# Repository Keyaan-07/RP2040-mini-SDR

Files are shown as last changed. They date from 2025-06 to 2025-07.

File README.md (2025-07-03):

# RP2040 Mini SDR
This is an SDR, as the name says, and it can function in the FM, Airband and NOAA-APT bands ONLY AS A RECEIVER. This is completely legal to make and use.  
I have used RP2040 and ADE-11X+ mixer and SI5351 controllable clock. I thought that i would use a PCB trace USB but then i didn't do it because it would make the board cost go BOOOOM. So, normal USB-A.

I am in no way an RF expert and would love it if someone pointed out my errors and mailed them to [me](mailto:keyaan.1911@gmail.com) or DM on [hackclub](https://hackclub.com) Slack ```@Keyaan```

I think I am gonna make another RF board that could legally transmit too! but that's just an idea for now. 

I am not making a 3D model for this project as i feel this is not required for now. 

## Why I chose to make this project
I have always wanted to try out stuff with RF, especially receiving images from NOAA with my own stuff(I have used [WebSDRs](https://websdr.org) before).  
So i thought that why not make it FM too. And then GPT told me i could legally listen to airband signals too. 

So, i planned to make out an SDR using the goated RP2040 chip and a few mixers and oscillators.  

I have used an SMA connector as it is the most common one i think. 

## How to make and bake it!
Your take the gerber files from this repository and then you upload them to your desired PCB manufacturer. I am using [PCB Power](htttps://pcbpower.com) as they support hcb cards and are only about 350km from my home. and you also order the parts listen in the BOM, i wont order everything, as i have a few things from my previous orders. so, in the BOM, there is Do Not Order column(DNO) that shows what i wont order but you would have to order if you wanna make it. Then you prep the PCB with solder paste. Then you just use the ibom from this repo and place the components and bake it up.

I have set prices to 0 for the components that i have already but i have linked them down.

# Images:
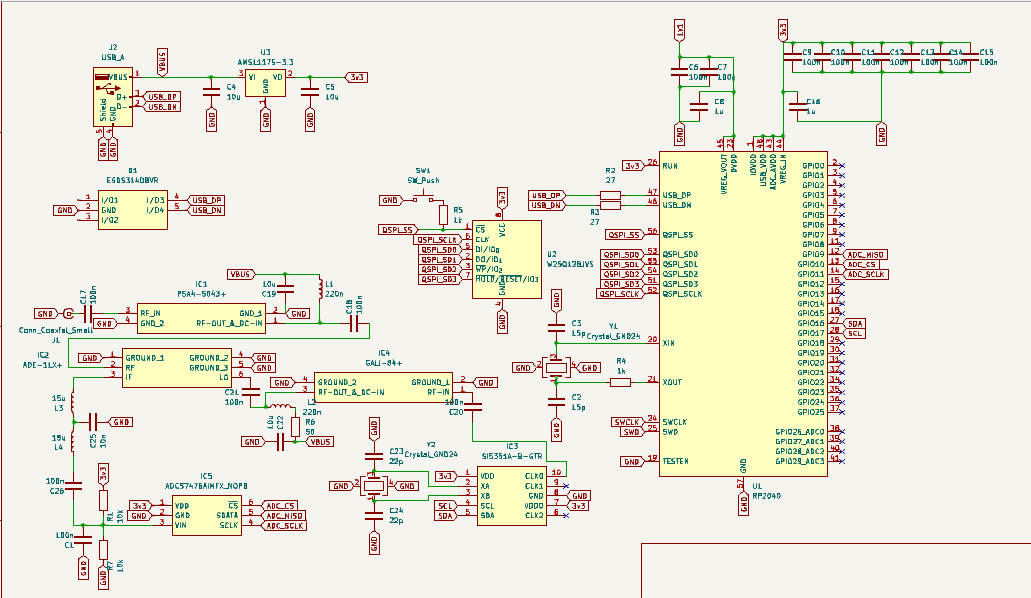
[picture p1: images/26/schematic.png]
Schematic


PCB final prolly

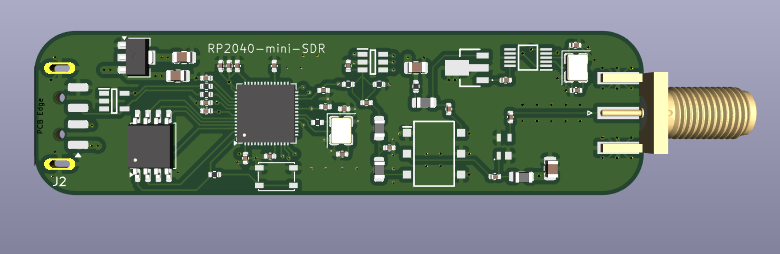
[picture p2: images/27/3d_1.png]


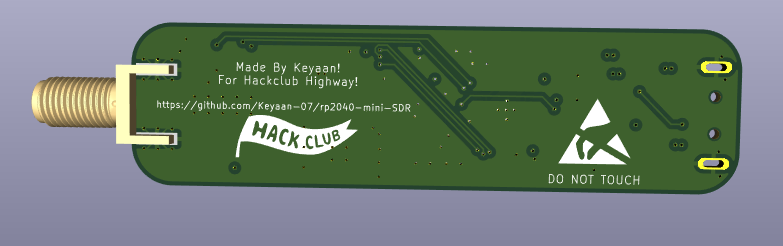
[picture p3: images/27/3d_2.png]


# BOM
|ITEM NAME |ITEM PRICE|FUNCTION |URL |OTHERS|
|---|---|---|---|---|
|PCB Manufacturing(4 Layer)+Stencil|$29.14 |The Main PCB + Stencil |https://jlcpcb.com | | | |
|PCB Components |$23.49 |Components on PCB |https://lcsc.com | |
|Tape Measure and SMA Cable|$5.57 |tape measure for a dipole antenna and sma to connect it to the PCB|https://www.amazon.in/FREEMANS-IKON-5m-Unbreakable-Bi-material/dp/B010M5GQ78/ , https://www.amazon.in/3AN-Telecom-Coaxial-Extension-Security/dp/B08GKXS915/| |
|Total |$58.20 | | | |  

### Update 2: i updated the stencil to be ordered from jlcpcb instead of pcbpower, as it was wayy expensive. Thank You.

### Update: I updated the pcb manufacturer from pcbpower to jlcpcb as pcbpower was way too expensive, and i didn't change the stencil if i add stencil on jlcpcb, the stencil+pcb would jump from $15 to $52 because shipping would be so much more, so i will order pcb from jlc for $15 incl. shipping and the stencil from pcbpower only because that would make it overall cheaper. Basically both from jlc would have been $52 and pcb from jlc and stencil form pcbpower is $42, so we save $10.
----
### Note: There are a few resistors and capacitors, which had very high minimum order quantity(MOQ), about 100 pieces so i had to forcefully include those, which i will be utilising in my next highway projects. And tbh the prices were very less(about $0.002 per piece) so i think it is alright.

# PCB Component Breakdown

|Id |Designator |Designation |MPN |Footprint |DNO - Do Not Order|DNP|MOQ|price |Quantity|Amount|LCSC Part No.|Supplier Link |
|---|---|---|---|---|---|---|---|---|---|---|---|---|
|1  |C1, C10, C11, C12, C13, C14, C15, C17, C18, C20, C21, C26, C6, C7, C9|100n |GRM155R61H104JE14D |402 |Yes |No |-  |0 |15 |0 | |https://lcsc.com/product-detail/Multilayer-Ceramic-Capacitors-MLCC-SMD-SMT_Murata-Electronics-GRM155R61H104JE14D_C426067.html |
|2  |C16, C8 |1u |GRM155R61H105KE05D |402 |Yes |No |-  |0 |2 |0 | |https://lcsc.com/product-detail/Multilayer-Ceramic-Capacitors-MLCC-SMD-SMT_Murata-Electronics-GRM155R61H105KE05D_C1518208.html |
|3  |C19, C22, C4, C5 |10u |CL21A106KBYQNNE |805 |No |No |Yes|0.0509|10 |0.509 | |https://lcsc.com/product-detail/Multilayer-Ceramic-Capacitors-MLCC-SMD-SMT_Samsung-Electro-Mechanics-CL21A106KBYQNNE_C2932476.html|
|4  |C2, C3 |15p |GJM1555C1H150FB01D |402 |Yes |No |-  |0 |2 |0 | |https://lcsc.com/product-detail/Multilayer-Ceramic-Capacitors-MLCC-SMD-SMT_Murata-Electronics-GJM1555C1H150FB01D_C441742.html |
|5  |C23, C24 |22p |GJM1555C1H220FB01D |402 |No |No |Yes|0.0379|20 |0.758 | |https://lcsc.com/product-detail/Multilayer-Ceramic-Capacitors-MLCC-SMD-SMT_Murata-Electronics-GJM1555C1H220FB01D_C882567.html |
|6  |C25 |10n |CC0402JRX7R9BB103 |402 |No |No |Yes|0.0016|100 |0.16  | |https://lcsc.com/product-detail/Multilayer-Ceramic-Capacitors-MLCC-SMD-SMT_YAGEO-CC0402JRX7R9BB103_C272878.html |
|7  |D1 |ESDS314DBVR |ESDS314DBVR |ESDS314BVR_SOT95P280X145-5N |Yes |No |-  |0 |1 |0 | |https://lcsc.com/product-detail/ESD-and-Surge-Protection-TVS-ESD_Texas-Instruments-ESDS314DBVR_C1847859.html |
|8  |IC1 |PSA4-5043+ |PSA4-5043+ |PSA45043 |No |No |No |2.22  |1 |2.22  | |https://lcsc.com/product-detail/RF-Amplifiers_Mini-Circuits-PSA4-5043_C5240848.html |
|9  |IC2 |ADE-11X+ |ADE-11X+ |ADE-11X+_SOTFL254P691X284-6N |No |No |No |4.87  |1 |4.87  | |https://lcsc.com/product-detail/RF-Mixers_Mini-Circuits-ADE-11X_C3176636.html |
|10 |IC3 |SI5351A-B-GTR |SI5351A-B-GTR |SI5351_SOP50P490X110-10N |No |No |No |0.92  |1 |0.92  | |https://lcsc.com/product-detail/Clock-Generators-PLLs-Frequency-Synthesizers_SKYWORKS-SILICON-LABS-SI5351A-B-GTR_C504891.html |
|11 |IC4 |GALI-84+ |GALI-84+ |GALI5 |No |No |No |4.3 |1 |4.3 | |https://lcsc.com/product-detail/RF-Amplifiers_Mini-Circuits-GALI-84_C3193261.html |
|12 |IC5 |ADCS7476AIMFX_NOPB|ADCS7476AIMFX_NOPB |ADCS7476_SOT95P280X145-6N |No |No |No |1.9 |1 |1.9 | |https://lcsc.com/product-detail/Analog-to-Digital-Converters-ADC_Texas-Instruments-ADCS7476AIMFX-NOPB_C91530.html |
|13 |J1 |Conn_Coaxial_Small|BWSMA-KE-P001 |SMA_Amphenol_132289_EdgeMount |No |No |No |0.38  |1 |0.38  | |https://lcsc.com/product-detail/Coaxial-Connectors-RF_BAT-WIRELESS-BWSMA-KE-P001_C496550.html |
|14 |J2 |USB_A |USB-212-BCW |USB_A_Connfly_DS1098_Horizontal |No |No |Yes|0.0819|5 |0.4095| |https://lcsc.com/product-detail/USB-Connectors_XUNPU-USB-212-BCW_C720521.html |
|15 |L1, L2 |220n |FEC0805CP-R22G-LRH |805 |No |No |Yes|0.0618|10 |0.618 | |https://lcsc.com/product-detail/Inductors-SMD_PSA-Prosperity-Dielectrics-FEC0805CP-R22G-LRH_C346387.html |
|16 |L3, L4 |15u |YWLD2012-150K |805 |No |No |Yes|0.0391|10 |0.391 | |https://lcsc.com/product-detail/Inductors-SMD_YJYCOIN-YWLD2012-150K_C5339219.html |
|17 |R1, R7 |10k |RCS040210K0FKED |402 |Yes |No |-  |0 |2 |0 | |https://lcsc.com/product-detail/Chip-Resistor-Surface-Mount_Vishay-Intertech-RCS040210K0FKED_C3020235.html |
|18 |R2, R3 |27 |ERJ2GEJ270X |402 |Yes |No |-  |0 |2 |0 | |https://lcsc.com/product-detail/Chip-Resistor-Surface-Mount_PANASONIC-ERJ2GEJ270X_C278580.html |
|19 |R4, R5 |1k |ERJPA2F1001X |402 |Yes |No |-  |0 |2 |0 | |https://lcsc.com/product-detail/Chip-Resistor-Surface-Mount_PANASONIC-ERJPA2F1001X_C427241.html |
|20 |R6 |50 |RT0402BRE0750RL |402 |No |No |Yes|0.0207|20 |0.414 | |https://lcsc.com/product-detail/Chip-Resistor-Surface-Mount_YAGEO-RT0402BRE0750RL_C853312.html |
|21 |SW1 |SW_Push |PTS810SJM250SMTRLFS |SW_SPST_PTS810 |No |No |No |0.6 |3 |1.8 | |https://lcsc.com/product-detail/Tactile-Switches_C-K-PTS810SJM250SMTRLFS_C116501.html |
|22 |U1 |RP2040 |RP2040 |QFN-56-1EP_7x7mm_P0.4mm_EP3.2x3.2mm|No |No |No |1.131 |1 |1.131 | |https://lcsc.com/product-detail/Microcontrollers-MCU-MPU-SOC_Raspberry-Pi-RP2040_C2040.html |
|23 |U2 |W25Q128JVS |W25Q128JVS |SOIC-8_5.3x5.3mm_P1.27mm |Yes |No |-  |0 |1 |0 | |https://lcsc.com/product-detail/NOR-FLASH_Winbond-Elec-W25Q128JVSIM_C2613930.html |
|24 |U3 |AMS1117S-3.3 |AMS1117S-3.3 |SOT-89-3 |yes |No |-  |0 |1 |0 | |https://lcsc.com/product-detail/Voltage-Regulators-Linear-Low-Drop-Out-LDO-Regulators_JSMSEMI-AMS1117S-3-3_C917152.html |
|25 |Y1 |Crystal_GND24 |ABM8-272-T3 |Crystal_SMD_3225-4Pin_3.2x2.5mm |No |No |No |0.3731|2 |0.7462| | |
|26 |Y2 |Crystal_GND24 |XXGBBCNANF-25.000000MHZ|Crystal_SMD_3225-4Pin_3.2x2.5mm |No |No |Yes|0.1459|5 |0.7295| |https://lcsc.com/product-detail/Crystals_TAITIEN-Elec-XXGBBCNANF-25-000000MHZ_C521601.html |
| |Rounding Errors |1.2338 |USD | | | | | | | | | |
| |Shipping |3.74 |USD | | | | | | | | | |
| |Total |23.49 |USD | | | | | | | | | |

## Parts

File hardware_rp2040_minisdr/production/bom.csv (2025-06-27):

Designator | Footprint | Quantity | Value | LCSC Part #
C1, C10, C11, C12, C13, C14, C15, C17, C18, C20, C21, C26, C6, C7, C9 | 402 | 15 | 100n
C16, C8 | 402 | 2 | 1u
C19, C22, C4, C5 | 805 | 4 | 10u
C2, C3 | 402 | 2 | 15p
C23, C24 | 402 | 2 | 22p
C25 | 402 | 1 | 10n
D1 | ESDS314BVR_SOT95P280X145-5N | 1 | ESDS314DBVR
IC1 | PSA45043 | 1 | PSA4-5043+
IC2 | ADE-11X+_SOTFL254P691X284-6N | 1 | ADE-11X+
IC3 | SI5351_SOP50P490X110-10N | 1 | SI5351A-B-GTR
IC4 | GALI5 | 1 | GALI-84+
IC5 | ADCS7476_SOT95P280X145-6N | 1 | ADCS7476AIMFX_NOPB
J1 | SMA_Amphenol_132289_EdgeMount | 1 | Conn_Coaxial_Small
J2 | USB_A_Connfly_DS1098_Horizontal | 1 | USB_A
L1, L2 | 805 | 2 | 220n
L3, L4 | 805 | 2 | 15u
R1, R7 | 402 | 2 | 10k
R2, R3 | 402 | 2 | 27
R4, R5 | 402 | 2 | 1k
R6 | 402 | 1 | 50
SW1 | SW_SPST_PTS810 | 1 | SW_Push
U1 | QFN-56-1EP_7x7mm_P0.4mm_EP3.2x3.2mm | 1 | RP2040
U2 | SOIC-8_5.3x5.3mm_P1.27mm | 1 | W25Q128JVS
U3 | SOT-89-3 | 1 | AMS1117S-3.3
Y1, Y2 | Crystal_SMD_3225-4Pin_3.2x2.5mm | 2 | Crystal_GND24

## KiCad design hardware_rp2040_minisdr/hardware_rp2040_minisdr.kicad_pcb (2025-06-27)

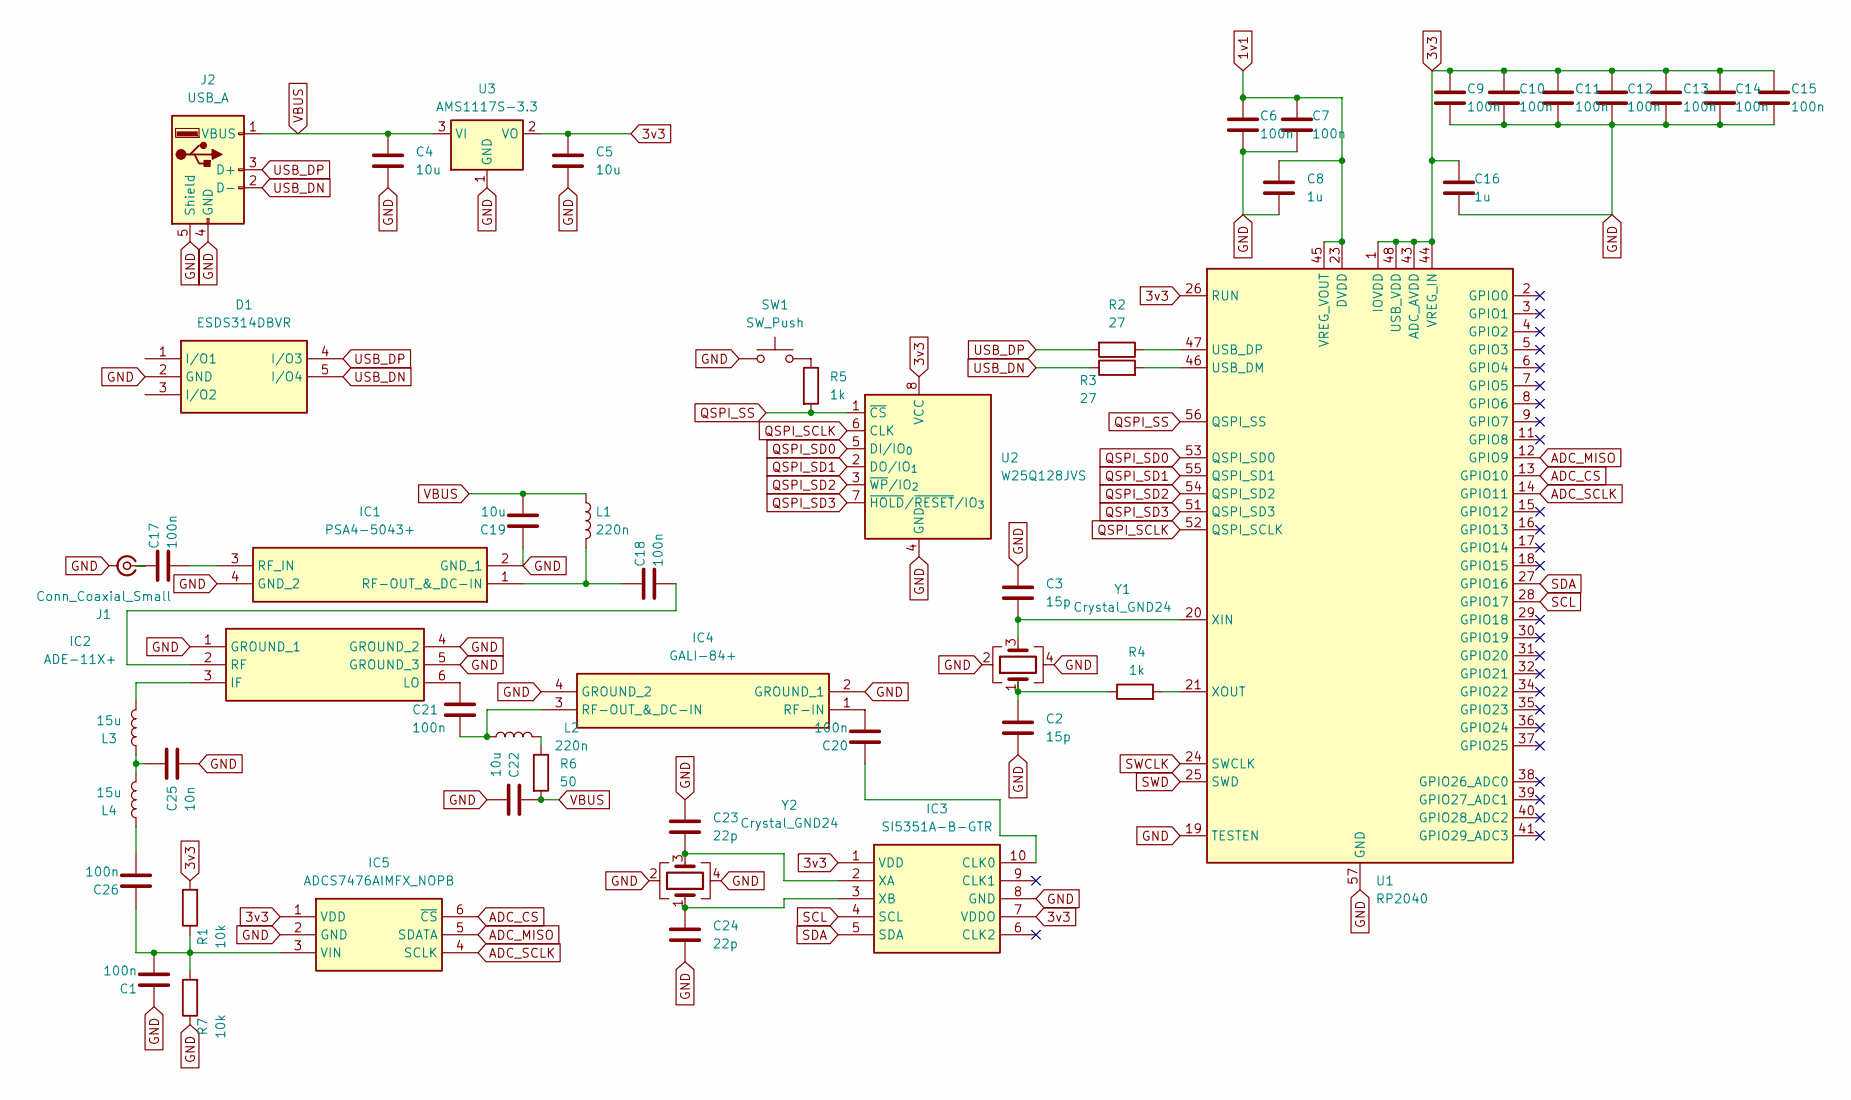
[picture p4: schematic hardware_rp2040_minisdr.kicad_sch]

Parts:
C1, C6, C7, C9, C10, C11, C12, C13, C14, C15, C17, C18, C20, C21, C26: 100n; C_0402_1005Metric
C2, C3: 15p; C_0402_1005Metric
C4, C5, C19, C22: 10u; C_0805_2012Metric
C8, C16: 1u; C_0402_1005Metric
C23, C24: 22p; C_0402_1005Metric
C25: 10n; C_0402_1005Metric
D1: ESDS314DBVR; ESDS314BVR_SOT95P280X145-5N; Mouser Part Number 595-ESDS314DBVR
IC1: PSA4-5043+; PSA45043; Mouser Part Number 139-PSA4-5043
IC2: ADE-11X+; ADE-11X+_SOTFL254P691X284-6N; Mouser Part Number 139-ADE-11X
IC3: SI5351A-B-GTR; SI5351_SOP50P490X110-10N; Mouser Part Number 634-SI5351A-B-GTR
IC4: GALI-84+; GALI5; Mouser Part Number 139-GALI-84
IC5: ADCS7476AIMFX_NOPB; ADCS7476_SOT95P280X145-6N; Mouser Part Number 926-ADCS7476AIMFXNPB
J1: Conn_Coaxial_Small; SMA_Amphenol_132289_EdgeMount
J2: USB_A; USB_A_Connfly_DS1098_Horizontal
L1, L2: 220n; L_0805_2012Metric
L3, L4: 15u; L_0805_2012Metric
R1, R7: 10k; R_0402_1005Metric
R2, R3: 27; R_0402_1005Metric
R4, R5: 1k; R_0402_1005Metric
R6: 50; R_0402_1005Metric
SW1: SW_Push; SW_SPST_PTS810
U1: RP2040; QFN-56-1EP_7x7mm_P0.4mm_EP3.2x3.2mm
U2: W25Q128JVS; SOIC-8_5.3x5.3mm_P1.27mm
U3: AMS1117S-3.3; SOT-89-3
Y1, Y2: Crystal_GND24; Crystal_SMD_3225-4Pin_3.2x2.5mm

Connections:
1v1: C6.1, C7.1, C8.1, U1.23 (DVDD), U1.45 (VREG_VOUT), U1.50 (DVDD)
3v3: C5.1, C9.1, C10.1, C11.1, C12.1, C13.1, C14.1, C15.1, C16.1, IC3.1 (VDD), IC3.7 (VDDO), IC5.1 (VDD), R1.2, U1.1 (IOVDD), U1.10 (IOVDD), U1.22 (IOVDD), U1.26 (RUN), U1.33 (IOVDD), U1.42 (IOVDD), U1.43 (ADC_AVDD), U1.44 (VREG_IN), U1.48 (USB_VDD), U1.49 (IOVDD), U2.8 (VCC), U3.2 (VO)
ADC_CS: IC5.6 (~CS), U1.13 (GPIO10)
ADC_MISO: IC5.5 (SDATA), U1.12 (GPIO9)
ADC_SCLK: IC5.4 (SCLK), U1.14 (GPIO11)
GND: C1.1, C2.2, C3.1, C4.2, C5.2, C6.2, C7.2, C8.2, C9.2, C10.2, C11.2, C12.2, C13.2, C14.2, C15.2, C16.2, C19.1, C22.2, C23.1, C24.2, C25.2, D1.2 (GND), IC1.2 (GND_1), IC1.4 (GND_2), IC2.1 (GROUND_1), IC2.4 (GROUND_2), IC2.5 (GROUND_3), IC3.8 (GND), IC4.2 (GROUND_1), IC4.4 (GROUND_2), IC5.2 (GND), J1.2 (Ext), J2.4 (GND), J2.5 (Shield), R7.1, SW1.1, U1.19 (TESTEN), U1.57 (GND), U2.4 (GND), U3.1 (GND), Y1.2, Y1.4, Y2.2, Y2.4
unnamed: C2.1, R4.1, Y1.1
unnamed: C25.1, L3.1, L4.2
unnamed: C26.2, L4.1
unnamed: C18.1, IC1.1 (RF-OUT_&_DC-IN), L1.2
unnamed: C17.2, IC1.3 (RF_IN)
unnamed: IC2.3 (IF), L3.2
unnamed: C21.1, IC2.6 (LO)
unnamed: C18.2, IC2.2 (RF)
unnamed: C20.1, IC3.10 (CLK0)
unnamed: C23.2, IC3.2 (XA), Y2.3
unnamed: C24.1, IC3.3 (XB), Y2.1
unnamed: C20.2, IC4.1 (RF-IN)
unnamed: C21.2, IC4.3 (RF-OUT_&_DC-IN), L2.1
unnamed: C1.2, C26.1, IC5.3 (VIN), R1.1, R7.2
unnamed: C17.1, J1.1 (In)
unnamed: L2.2, R6.1
unnamed: R5.1, SW1.2
unnamed: R3.2, U1.46 (USB_DM)
unnamed: R2.1, U1.47 (USB_DP)
unnamed: C3.2, U1.20 (XIN), Y1.3
unnamed: R4.2, U1.21 (XOUT)
QSPI_SCLK: U1.52 (QSPI_SCLK), U2.6 (CLK)
QSPI_SD0: U1.53 (QSPI_SD0), U2.5 (DI/IO_{0})
QSPI_SD1: U1.55 (QSPI_SD1), U2.2 (DO/IO_{1})
QSPI_SD2: U1.54 (QSPI_SD2), U2.3 (~WP/IO_{2})
QSPI_SD3: U1.51 (QSPI_SD3), U2.7 (~HOLD/~RESET/IO_{3})
QSPI_SS: R5.2, U1.56 (QSPI_SS), U2.1 (~CS)
SCL: IC3.4 (SCL), U1.28 (GPIO17)
SDA: IC3.5 (SDA), U1.27 (GPIO16)
SWCLK: U1.24 (SWCLK)
SWD: U1.25 (SWD)
USB_DN: D1.5 (I/O4), J2.2 (D-), R3.1
USB_DP: D1.4 (I/O3), J2.3 (D+), R2.2
VBUS: C4.1, C19.2, C22.1, J2.1 (VBUS), L1.1, R6.2, U3.3 (VI)

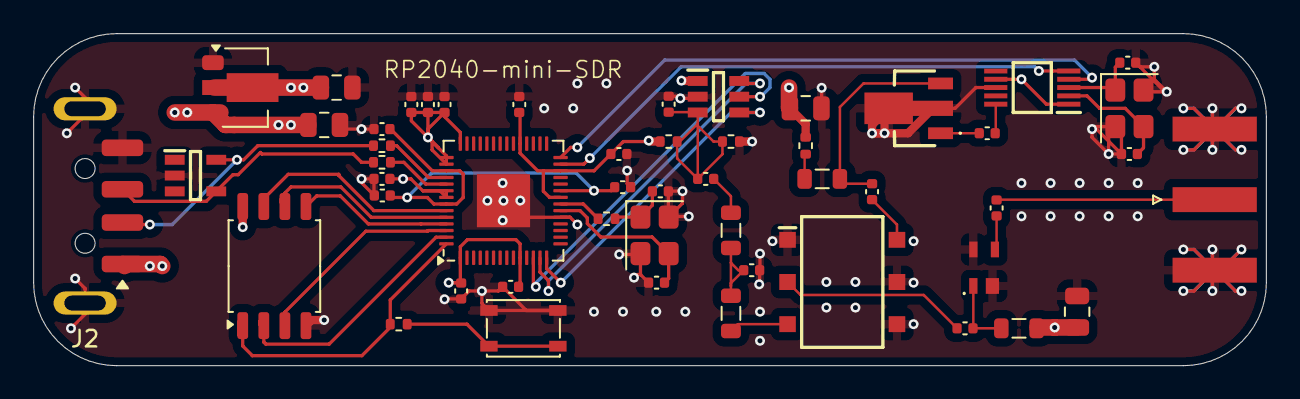
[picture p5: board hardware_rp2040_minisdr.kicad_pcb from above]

Board: 4 copper layers, 74.2 x 20.0 mm, 51 parts (0 on the bottom side), 38 nets.

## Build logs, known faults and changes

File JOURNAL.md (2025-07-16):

---
title: "RP2040 mini SDR"
author: "Keyaan"
description: "A Receive-only mini SDR capable of decoding FM, AM(Airband) and NOAA APT"
created_at: "2025-06-16"
---
----
# Total Time Spent: About 12 hours and 15 mins. 

# 16 June 2025

Okay, so i have thought of making an SDR, and yeah, i would love to make one using the Great RP2040. The idea is very rough yet, i have to work on it too much

What I(and a little bit of gpt) came up with:
#### this is [excalidraw](https://excalidraw.com) btw

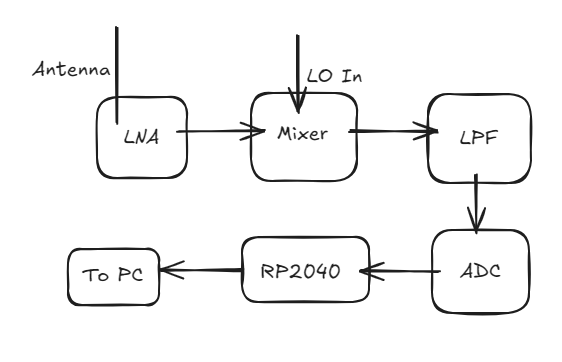
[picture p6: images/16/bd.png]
Block Diag


### Time Spent Today: 30 mins
----
# 18 June 2025

Okay, so today i found a few components for the mini SDR. Here they are:  
LNA: PSA4-5043+  
Mixer: ADE-11X+  
ADC: ADCS7676 (old: ADS7042)  
Processor/Controller: RP2040: Arguable the best MCU ever Made  

### Time Spent on June 18: About 1 hour
----
# 22 June 2025

I chose an LO. Here is the list of the updated parts:  
LNA: [PSA4-5043+](https://www.lcsc.com/product-detail/RF-Amplifiers_Mini-Circuits-PSA4-5043_C5240848.html)  
Mixer: [ADE-11X+](https://lcsc.com/product-detail/RF-Mixers_Mini-Circuits-ADE-11X_C3176636.html)  
LO: [Si5351](https://www.lcsc.com/product-detail/Clock-Generators-PLLs-Frequency-Synthesizers_SKYWORKS-SILICON-LABS-SI5351A-B-GTR_C504891.html)  
LO AMP: [GALI-84+](https://lcsc.com/product-detail/RF-Amplifiers_Mini-Circuits-GALI-84_C3193261.html)  
ADC: [ADCS7476](https://lcsc.com/product-detail/Analog-to-Digital-Converters-ADC_Texas-Instruments-ADCS7476AIMFX-NOPB_C91530.html) (old: [ADS7042](https://lcsc.com/product-detail/Analog-to-Digital-Converters-ADC_Texas-Instruments-ADS7042IDCUR_C701641.html))  
Processor: [RP2040](https://www.lcsc.com/product-detail/Microcontrollers-MCU-MPU-SOC_Raspberry-Pi-RP2040_C2040.html)  
Crystal for RP2040: [ABM8-272-T3](https://lcsc.com/product-detail/Crystals_Abracon-LLC-ABM8-272-T3_C20625731.html)   
LPF: Simple LC Circuit  
XTAL: [XXGBBCNANF-25.000000MHZ
](https://lcsc.com/product-detail/Crystals_TAITIEN-Elec-XXGBBCNANF-25-000000MHZ_C521601.html)  

### Updated Block DIag:
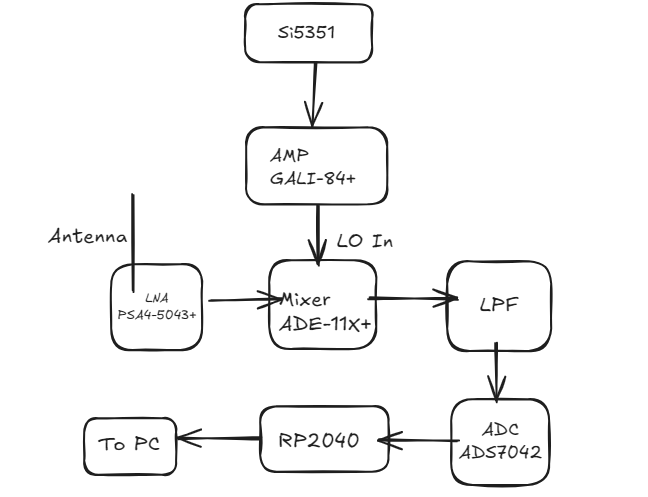
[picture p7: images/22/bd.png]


Umm okay, i did i BIT of schematic(or most of it cuz idk how much is left). Gonna take a break now, i think i might do some more later, so, will update the schematic later.

### Big Change: I am changing my ADC to the [ADCS7476](https://lcsc.com/product-detail/Analog-to-Digital-Converters-ADC_Texas-Instruments-ADCS7476AIMFX-NOPB_C91530.html)

Most of the schematic is now done. only connections to the rp2040 remaining prolly. Image:

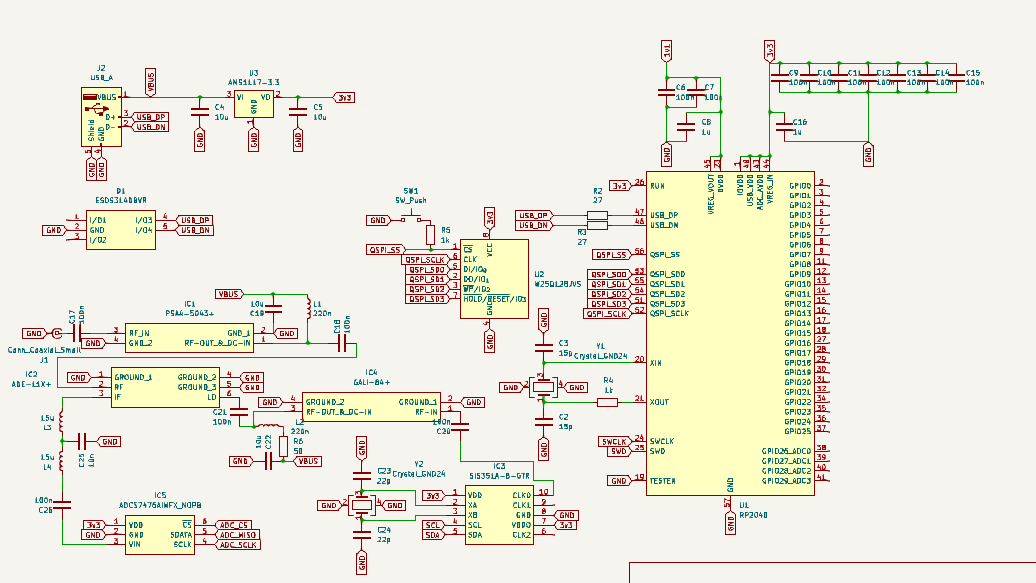
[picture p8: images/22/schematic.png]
schematic on 22 june
  
HELL YEAH! So much work done in a single day!!  

### Time Spent Today: 4 hours
----

# 23 June 2025

Yup, todya i am working on completing scheamtic, assigning and gathering footprints, and starting with the PCB. 

I want to make the footprint like Cyao has made in his [ESP-USB](https://github.com/cheyao/esp-usb). So i started out to make my own footprint, but after having less luck with myself, i just took it from [Cyao](https://github.com/cheyao/esp-usb/tree/main/hardware/esp-usb-lib.pretty). Hehehe thanks Cyao. This is the shit i thought i was cooking lol
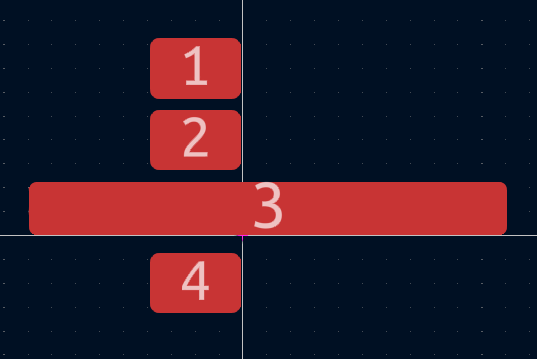
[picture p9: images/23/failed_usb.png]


I was thinking of using LEDs on SPI and I2C lines, but then GPT told me it was not ideal, so i did not simply put it!

oh yeah, btw i forgot to explain some stuff. This project uses a few RF ICs to convert the incoming frequencies into IF(Intermediate Frequency). This IF is then read by an ADC at 1 MSPS(Mega Samples Per second). ADC converts Analog values to digital values and RP2040 reads via SPI. this is then sent to PC where it is read by some other software.

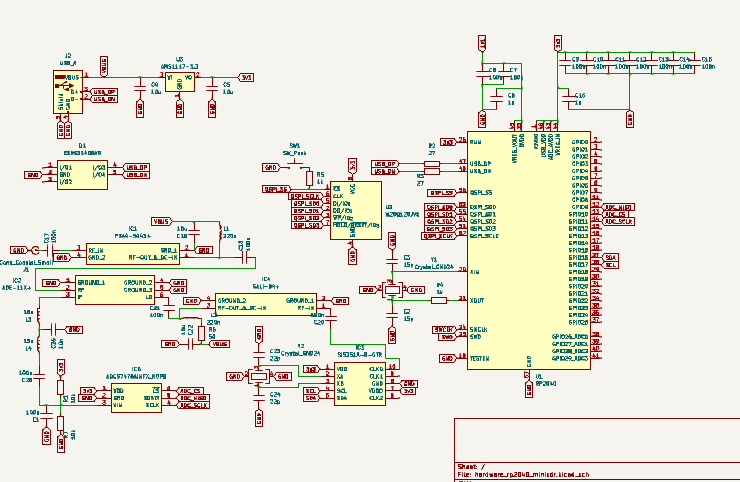
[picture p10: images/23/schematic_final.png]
final schematic


did a bit of PCB, will upload the images later
Here are the images: 
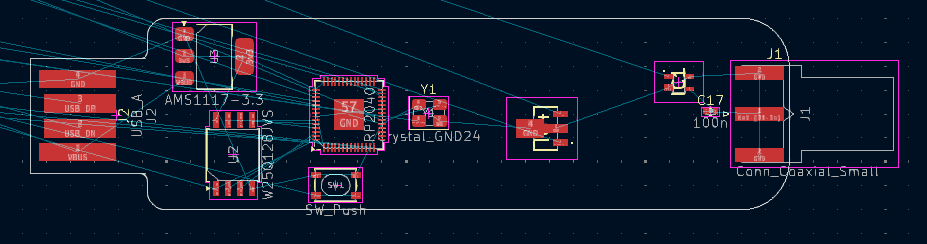
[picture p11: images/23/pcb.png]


### Total Time Spent Today: 2 hours 30 mins
----
# June 24 2025

Hell yeah, i worked on my PCB in the school today, i got permission to bring my laptop hahaha. here is the progress:

oh hell nah, i forgot the ss and continued further, so nvm, here is the current progress:
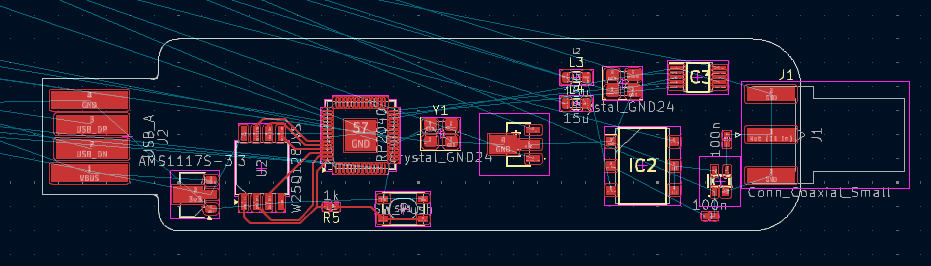
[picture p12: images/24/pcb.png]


worked a lot on the PCB, will update soon!!  
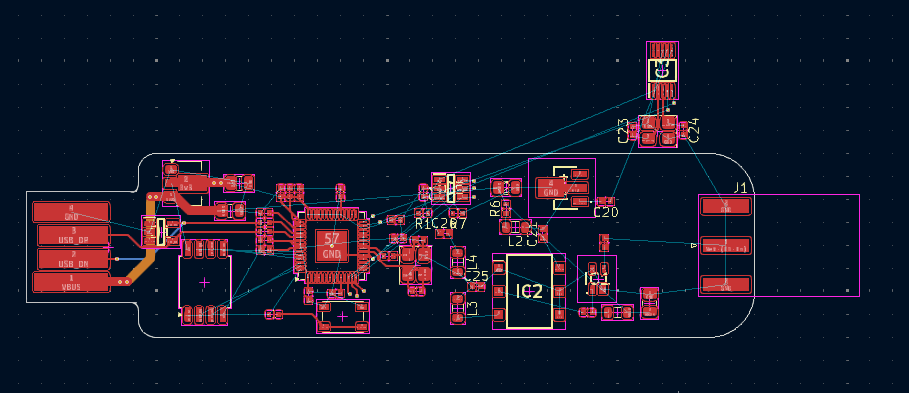
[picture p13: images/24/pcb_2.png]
Final PCB look on 24 June


### Time Spent Today: 1 hour 30 mins
----
# June 25 2025

Changed something on the schematic today that i dont remember. and also worked on the PCB. 

I always order from [PCB Power](pcbpower.com) and i found out they have their own page for controlled impedance trace widths, so i dont need to calculate anything for the RF Layout!!

I have plans to work today later but i have to study too so let's see, if i get time i will finish the routing part and then move on to BOM and README and submitting.  
Current Progress:  
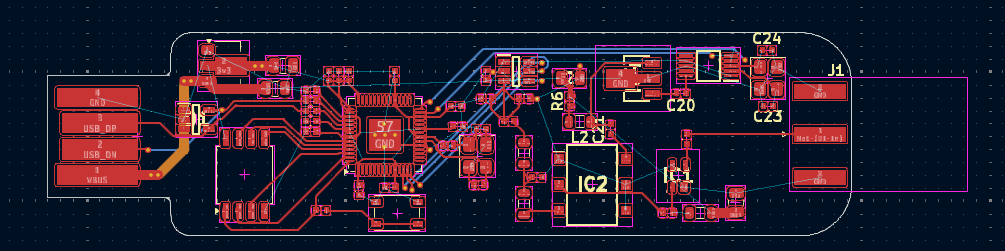
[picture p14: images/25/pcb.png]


I realised my mistake, for onboard USB connector, i will need to have the board 2.00 mm thick instead of 1.6mm thick, which is gonna increase the cost significantly, like the normal 4 layer board was about $45, but now if i order the same, it WILL be minimum $75, which i dont wanna give just for a single PCB, so instead i am gonna save costs and add the normal USB A Connector

Yay, i think i am doe with my PCB. all nets routed, all DRC errors un-errored(is that even a real word??) and wow, i can start working on the BOM from tomorrow. :))  
Da LOOK Of MA' QUEEN:  


### Time Spent Today: 45 mins
----
# June 26 2025

One of my friends suggested me that i should not have direct 90 deg VBUS connections, even though they are via a via. so i am gonna thange that rn

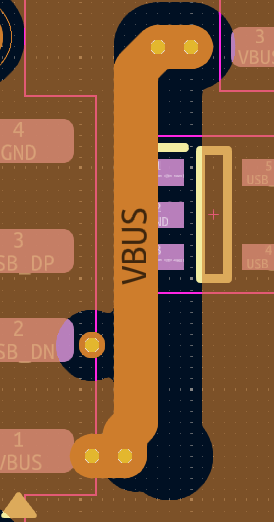
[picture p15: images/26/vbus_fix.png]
VBUS Fix


I believe this should be the final look of the PCB:  
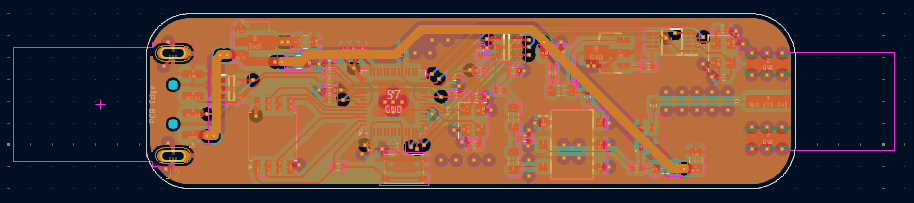
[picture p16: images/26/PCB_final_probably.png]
Final PCB


Final schematic:  
Schematic  
The 3D model of the PCB looks like this:  
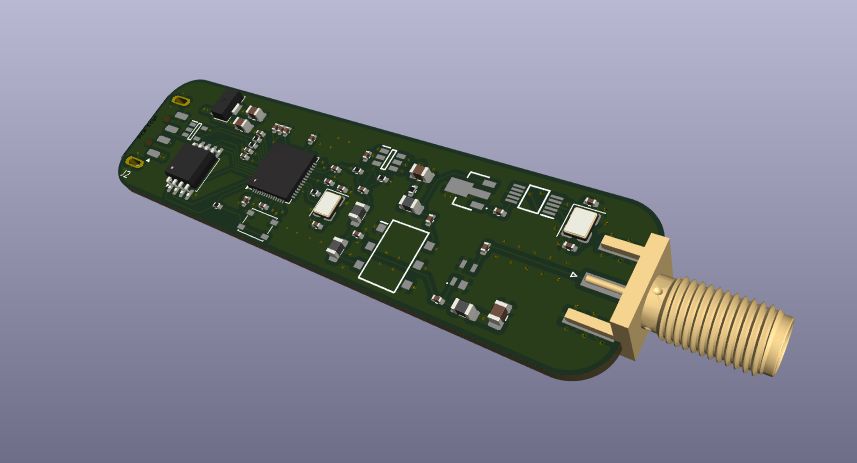
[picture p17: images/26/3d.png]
3d model
  
----
# June 27 2025

I forgot to add the silkscreen today, so now i added it, here it is:

PCB final prolly

3d model final prolly

3d model final prolly

Finally, all the work is done, now adding some final touches, all the BOM is made and all the PCBs are ready to be paid for, now i'll update the time for today, make an update in #highway-pitstop and submit!!!

### Time Spent Today: about 2 hours

# July 3
I updated the BOM for the second time today, and now the BOM is wayy optimised yayy

# July 16

PCBs arrived today along with stencil from JLC, yayayayya. i liked jlc so much that now i will always order from them. here are a few pics:

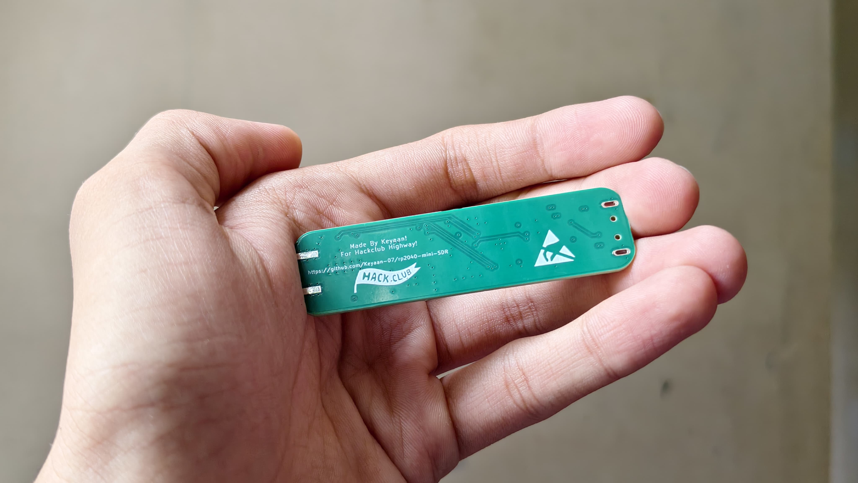
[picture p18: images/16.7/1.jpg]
PCB arrived 1!!!

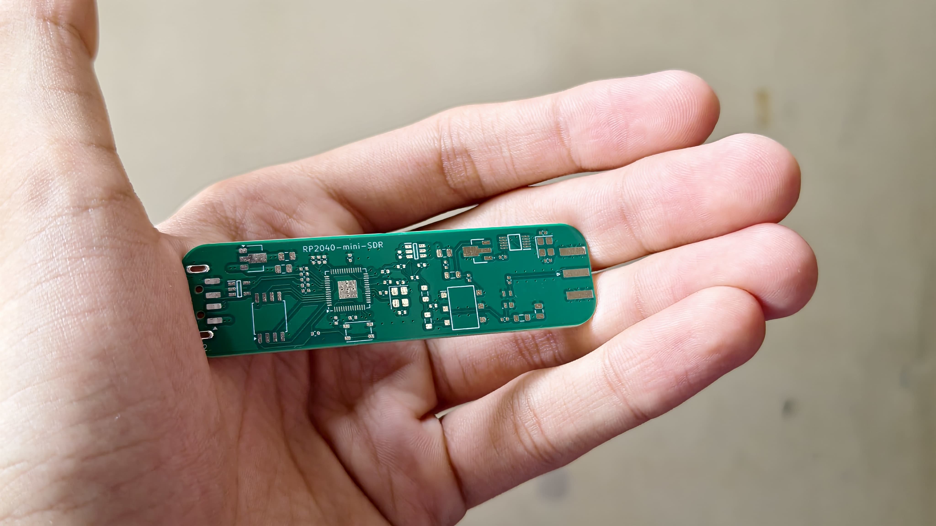
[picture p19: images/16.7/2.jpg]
PCB arrived 2!!!

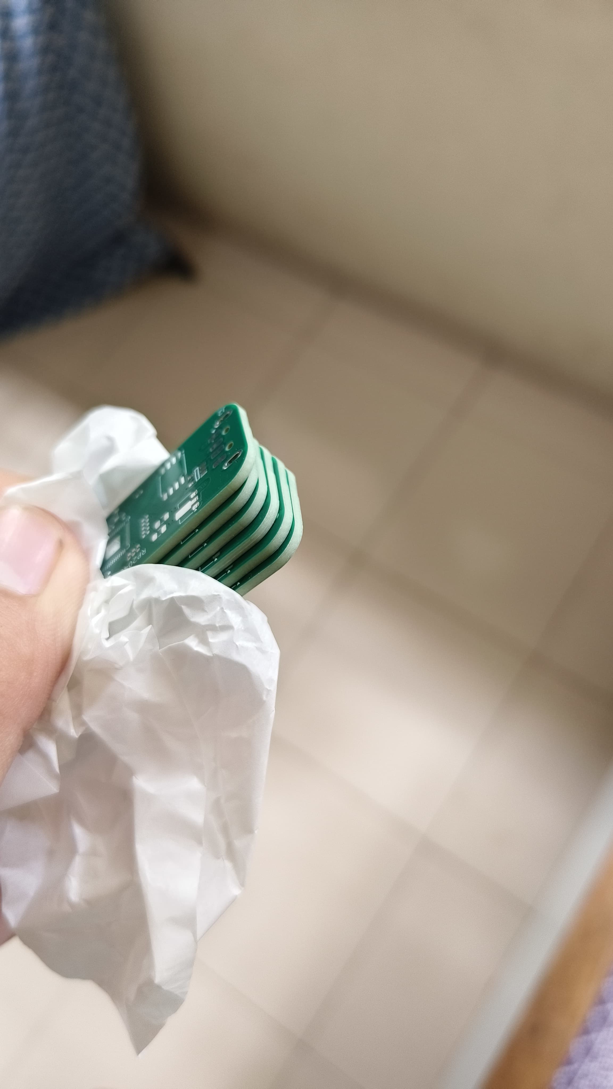
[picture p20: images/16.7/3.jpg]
PCB arrived 3!!!


IDK why but they sent me 6 pcbs, cyao told me this happened because they panelise the pcbs and sometimes it's their error on the manufacturing part, so they make an extra, so if no issues occur, they just send an extra pcb yayy!!

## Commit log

2025-06-18 Hardware Files
    [hardware_rp2040_minisdr.kicad_pcb, hardware_rp2040_minisdr.kicad_sch]
2025-06-22 started with schematic
    [hardware_rp2040_minisdr.kicad_sch]
2025-06-23 final schematic
2025-06-24 pcb placement
    [hardware_rp2040_minisdr.kicad_pcb, hardware_rp2040_minisdr.kicad_sch]
2025-06-24 pcb final inage on 24 june
2025-06-25 pcb journal
2025-06-25 pcb readyyy
2025-06-25 pcb hardware!
    [hardware_rp2040_minisdr.kicad_pcb, hardware_rp2040_minisdr.kicad_sch]
2025-06-26 final pcb probably journaling
2025-06-26 pcb final i think
2025-06-27 silkscreen stuff
    [bom.csv, designators.csv, hardware_rp2040_minisdr.kicad_pcb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]
2025-06-27 silkscreen designs
    [hardware_rp2040_minisdr.kicad_pcb]
2025-06-27 production files update
    [bom.csv, designators.csv]
2025-06-27 added Do not touch in silkscreen
    [hardware_rp2040_minisdr.kicad_pcb]
2025-06-27 pcb stencil output generated
    [hardware_rp2040_minisdr.kicad_pcb]
2025-06-27 BOM - WIP
    [BOM.csv]
2025-06-27 pcb doneeee
    [bom.csv]
2025-06-27 Added Total Cost
    [BOM.csv]
2025-06-27 Update total prices
    [pcb_components.csv]
2025-06-29 BOM updated
    [BOM.csv]
2025-07-03 BOM optimised
